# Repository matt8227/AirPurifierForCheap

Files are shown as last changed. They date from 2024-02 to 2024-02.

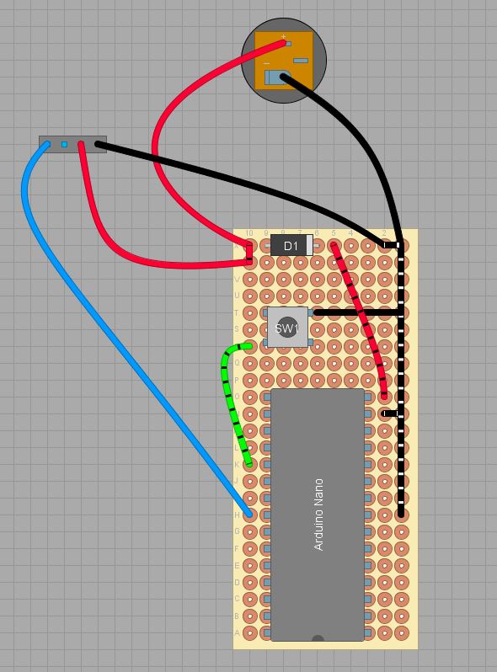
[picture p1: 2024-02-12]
Schematics/arduinoNanoFanController.JPG

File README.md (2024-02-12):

# AirPurifierForCheap
A collection of things I used to make some cheap air purifiers.

# Materials
- Round air purifier filter
- PC Fan
- Power Supply
- 3d printed box, adaptors and fan grill (optionally with a corner cut off)
- Barrel connector
- 4Pin fan connector
- Wires + solder
- Arduino Nano + buttons + perfboard + diode

# Idea
I wanted to make a couple of cheap air purifiers for my home.
I found bigclivedotcom's video on the subject (https://www.youtube.com/watch?v=6Vmh2Ip2Vxg) and decided to evolve his design by making the air purifier more controllable using the Arduino Nano, while also keeping the control components completely modular and removable from the filter for when it needs changing.

# Considerations
- For easy of printing the adaptors, try to find filters with a hole diameter that matches your fan diameter.
- If you want to use my box design, solder everything first, THEN put in place, it is much easier (and not so obvious to a soldering noob like me lol).
Another thing to consider is vibrations: my fans are quite bad in this aspect, so to reduce the chance of solder breaking I removed it from the assembly and set it on the floor to the side of the air purifier.
- The Arduino Nano use a linear voltage regulator to step down the voltage from the vin pin, so if you want to add functionalities that require power, consider you have a very strict budget in that regard (to be safe, a couple hundred mA). You may consider using a buck converter.
- I added the diode to protect the Nano from reverse polarity. It also has the nice benefit to slightly lower the input voltage and reduce the stress on the Nano voltage regulator.
 My fans seem to have that protection integrated. 
- Thank you BigClive for the idea!

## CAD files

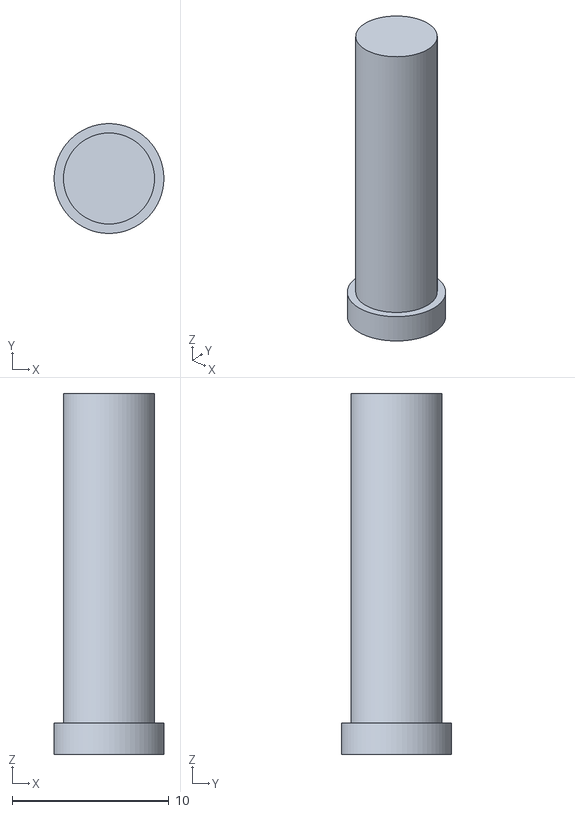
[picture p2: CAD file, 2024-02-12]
Models/ButtonPusher.stl
7.00 x 7.00 x 23.0

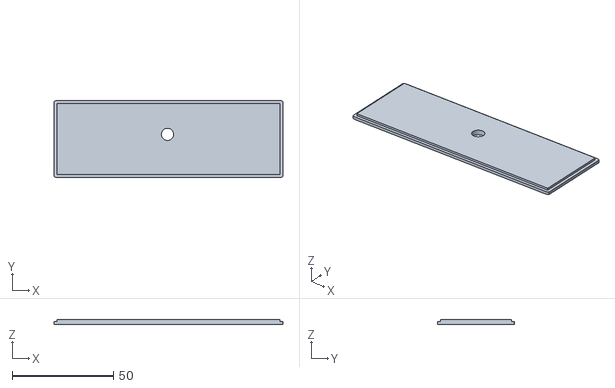
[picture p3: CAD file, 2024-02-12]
Models/LidWithHole.stl
113.0 x 38.0 x 2.40

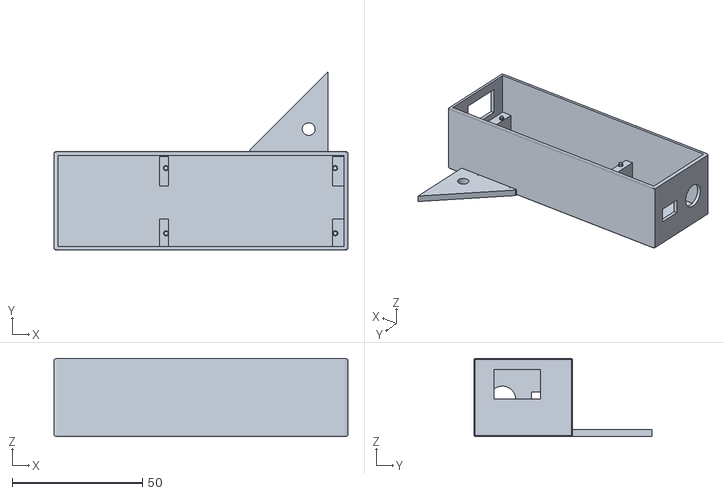
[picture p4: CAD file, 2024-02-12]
Models/BoxV3.stl
113.0 x 68.6 x 30.0

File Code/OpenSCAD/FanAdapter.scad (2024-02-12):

//CREDITS FOR THE ORIGINAL IDEA AND FILE GO TO BIGCLIVEDOTCOM


$fn = 100;

//-----------IMPORTANT-----------
buffer=0.01; //to help with removing skin effects openSCAD previews, set to 0 when rendering and/or exporting the STL file.
//--------------------------------

screw_hole_size = 4.9; //diameter of the screw hole
hole_distance = 7.5; //distance of the screw hole's center from the edge of the base

thickness = 1.5; //thickness of the parts
fan_size = 120; //size of the fan
filter_hole_diameter = 100; //diameter of the filter hole
insert_length = 14; //lenght of the insert into the filter hole

sealing_circle_length = 0; //extra diameter to be added onto the filter_hole_diameter to create a sealing circle (useful for filters with a foam sealant and/or when fan size is close to the filter hole diameter)

cone_steepness = 1.3;


cone = fan_size>filter_hole_diameter ? (fan_size-filter_hole_diameter)/cone_steepness : (filter_hole_diameter-fan_size)/cone_steepness;



difference()
{
	union()
	{
		//create base
		translate([0,0,0])
		cube([fan_size, fan_size, thickness]);
		
		//connecting cone
		translate([fan_size/2,fan_size/2,0])
        cylinder(h=cone, d1=fan_size, d2=filter_hole_diameter);
		
		//create sealing cylinder
		translate([fan_size/2,fan_size/2,cone])
		cylinder(h=thickness,d1=filter_hole_diameter+sealing_circle_length, d2=filter_hole_diameter+sealing_circle_length);
		
		//insert
		translate([fan_size/2,fan_size/2,cone])
		cylinder(h=insert_length,d=filter_hole_diameter);
	}
	//connecting cone
	translate([fan_size/2,fan_size/2,-buffer])
    cylinder(h=cone+2*buffer, d1=fan_size-(fan_size*1/30)+2*buffer, d2=filter_hole_diameter-2*thickness);
	
	//insert
	translate([fan_size/2,fan_size/2,cone-buffer])
    cylinder(h=insert_length+2*buffer,d=filter_hole_diameter-2*thickness);
	
	//create mounting holes
	translate([fan_size-hole_distance,fan_size-hole_distance,-buffer])
	cylinder(d=screw_hole_size,h=thickness+2*buffer);
	
	translate([hole_distance,fan_size-hole_distance,-buffer])
	cylinder(d=screw_hole_size,h=thickness+2*buffer);
	
	translate([fan_size-hole_distance,hole_distance,-buffer])
	cylinder(d=screw_hole_size,h=thickness+2*buffer);
	
	translate([hole_distance,hole_distance,-buffer])
	cylinder(d=screw_hole_size,h=thickness+2*buffer);
	
}

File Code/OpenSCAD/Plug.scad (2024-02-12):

//CREDITS OF THIS FILE GO TO BIG CLIVE FROM BIGCLIVEDOTCOM 
//link to his channel (https://www.youtube.com/@bigclivedotcom)


//HEPA filter blanking cap
$fn=100;
//You can adjust these four variables
//Mainly the filter hole diameter
filterhole=92;     //diameter of filter hole
rim=10;               //size of rim (10)
insert=10;          //Length of insert (10)
thickness=1.5;  //Thickness of plastic (1.5)
//Do not adjust anything below here
wall=(2*thickness);
cap=thickness+insert;
difference(){
union(){
//seal plate 
cylinder(h=thickness,d=filterhole+(2*rim));
//filter insert 
cylinder(h=cap,d=filterhole);
}
//filter insert core
translate([0,0,thickness])  
cylinder(h=cap+1,d=filterhole-wall);
}

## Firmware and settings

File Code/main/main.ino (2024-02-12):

//this is basically the state change example, modified to output a varying PWM signal. 

const int fanPin = 5;  

const int buttonPin = 2;  // the pin that the pushbutton is attached to
const int ledPin = 13;    // Use 13 for onboard LED,

int buttonState = 0;      // current state of the button
int lastButtonState = 0;  // previous state of the button

int fanSetting = 0;

//this array represents the various speeds the fan cicles through when pushing the button
//0 is off, while 255 is max speed. I experimented with values and set on these.
int fanSpeeds[5] = { 43, 80, 120, 160, 255 };


void setup() {
  // initialize the button pin as a input:
  pinMode(buttonPin, INPUT_PULLUP);
  // initialize the LED as an output:
  pinMode(ledPin, OUTPUT);
  pinMode(fanPin, OUTPUT);
  analogWrite(fanPin, fanSpeeds[0]);
  //Serial.begin(9600);
}


void loop() {
  // read the pushbutton input pin:
  buttonState = digitalRead(buttonPin);

  // compare the buttonState to its previous state
  if (buttonState != lastButtonState) {
    // if the state has changed, increment the counter
    if (buttonState == LOW) {
      // if the current state is HIGH then the button went from off to on:
      fanSetting++;
      if (fanSetting > 4) {
        fanSetting = 0;
      }
      analogWrite(fanPin, fanSpeeds[fanSetting]);
      //Serial.println(fanSpeeds[fanSetting]);

      digitalWrite(ledPin, HIGH);
    } else {
      digitalWrite(ledPin, LOW);
    }
    // Delay a little bit to avoid bouncing
    delay(50);
  }
  // save the current state as the last state, for next time through the loop
  lastButtonState = buttonState;
}

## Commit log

2024-02-12 Core stuff
    [BoxV3.stl, ButtonPusher.stl, LidWithHole.stl]
2024-02-12 OpenSCAD scripts
    Credits for the originals go to Clive from BigClivedotcom
    https://www.youtube.com/@bigclivedotcom
    [FanAdapter.scad, Plug.scad]
